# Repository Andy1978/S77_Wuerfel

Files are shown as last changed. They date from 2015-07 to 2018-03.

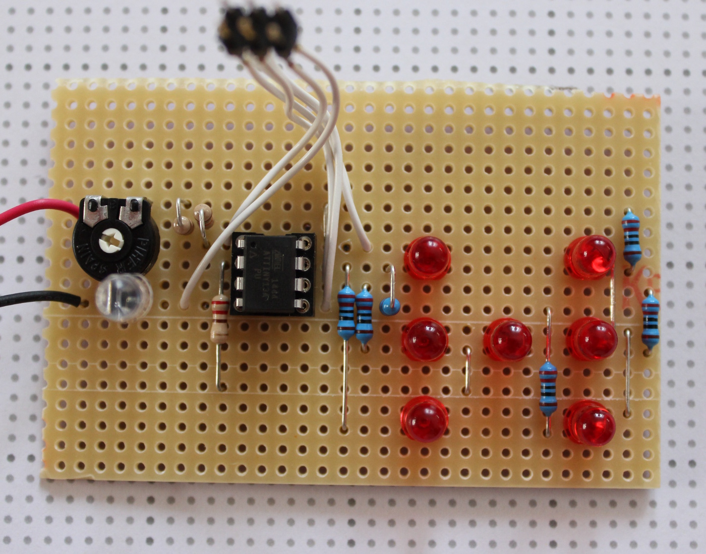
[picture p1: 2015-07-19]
doc/Aufbau.jpg

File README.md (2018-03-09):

# S77_Wuerfel
Elektronischer Würfel für den Section77 Lötkurs

http://tech-chat.de/files/VID_20150719_164159_Section77_Wuerfel.mp4

## Bauteile

Umgerechnet auf einen Bausatz

Anz. | Reichelt Bestellnummer | Bezeichnung                                | Preis
-----|------------------------|--------------------------------------------|-------
1    | ATTINY 13A-PU          | Atmel AVR-RISC-Controller                  | 0,99 €
7    | SLH 56 RT              | LED, 5mm, superhell, eingefärbt, klar, rot | 0,63 €
1    | BPW 40                 | Fototransistor, Plastikgehäuse, bedrahtet  | 0,29 €
7    | METALL 220             | Metallschichtwiderstand 220 Ohm            | 0,175 €
1    | METALL 12,0K           | Metallschichtwiderstand 12,0 K-Ohm         | 0,049 €
1    | GS 8P                  | IC-Sockel, 8-polig, superflach, gedreht, vergold. | 0,18 €
1    | TASTER 9302            | Kurzhubtaster 6x6mm, Höhe: 5,0mm, 12V, vertikal | 0,10 €
1    | H25SR160               | Streifenrasterplatine, Hartpapier, 160x100mm | 1,50 €, wird noch aufgeteilt
3    | aus GP AL40 AA         | Alkaline Mignon Aus 40er Pack              | 0,79€
1    | HALTER 3XUM3-DK        | Halter für 3 Mignonzellen (AA), Druckknopf | 0,40 €
1    | CLIP HQ9V-T            | Batterieclip für 9-Volt-Block, High-Quality, T-Form | 0,30€

## Abhängigkeiten unter GNU/Linux

* avr-gcc (Compiler für AVR µController)
* avr-libc
* avrdude (zum Übertragen der firmware)
* kicad (Für den Schaltplan)

In Debian basierten Distro z.B. über
```
sudo apt-get update
sudo apt-get install gcc-avr avr-libc avrdude kicad
```
zu installieren.

## Firmware compilieren und mit avrdude über USBasp flashen
```
cd src
make
make program
```

## udev rules für USBasp
```
$ cat /etc/udev/rules.d/45-avrusb.rules 
ATTRS{idVendor}=="16c0", ATTRS{idProduct}=="05dc", MODE="0660", GROUP="plugdev"
```

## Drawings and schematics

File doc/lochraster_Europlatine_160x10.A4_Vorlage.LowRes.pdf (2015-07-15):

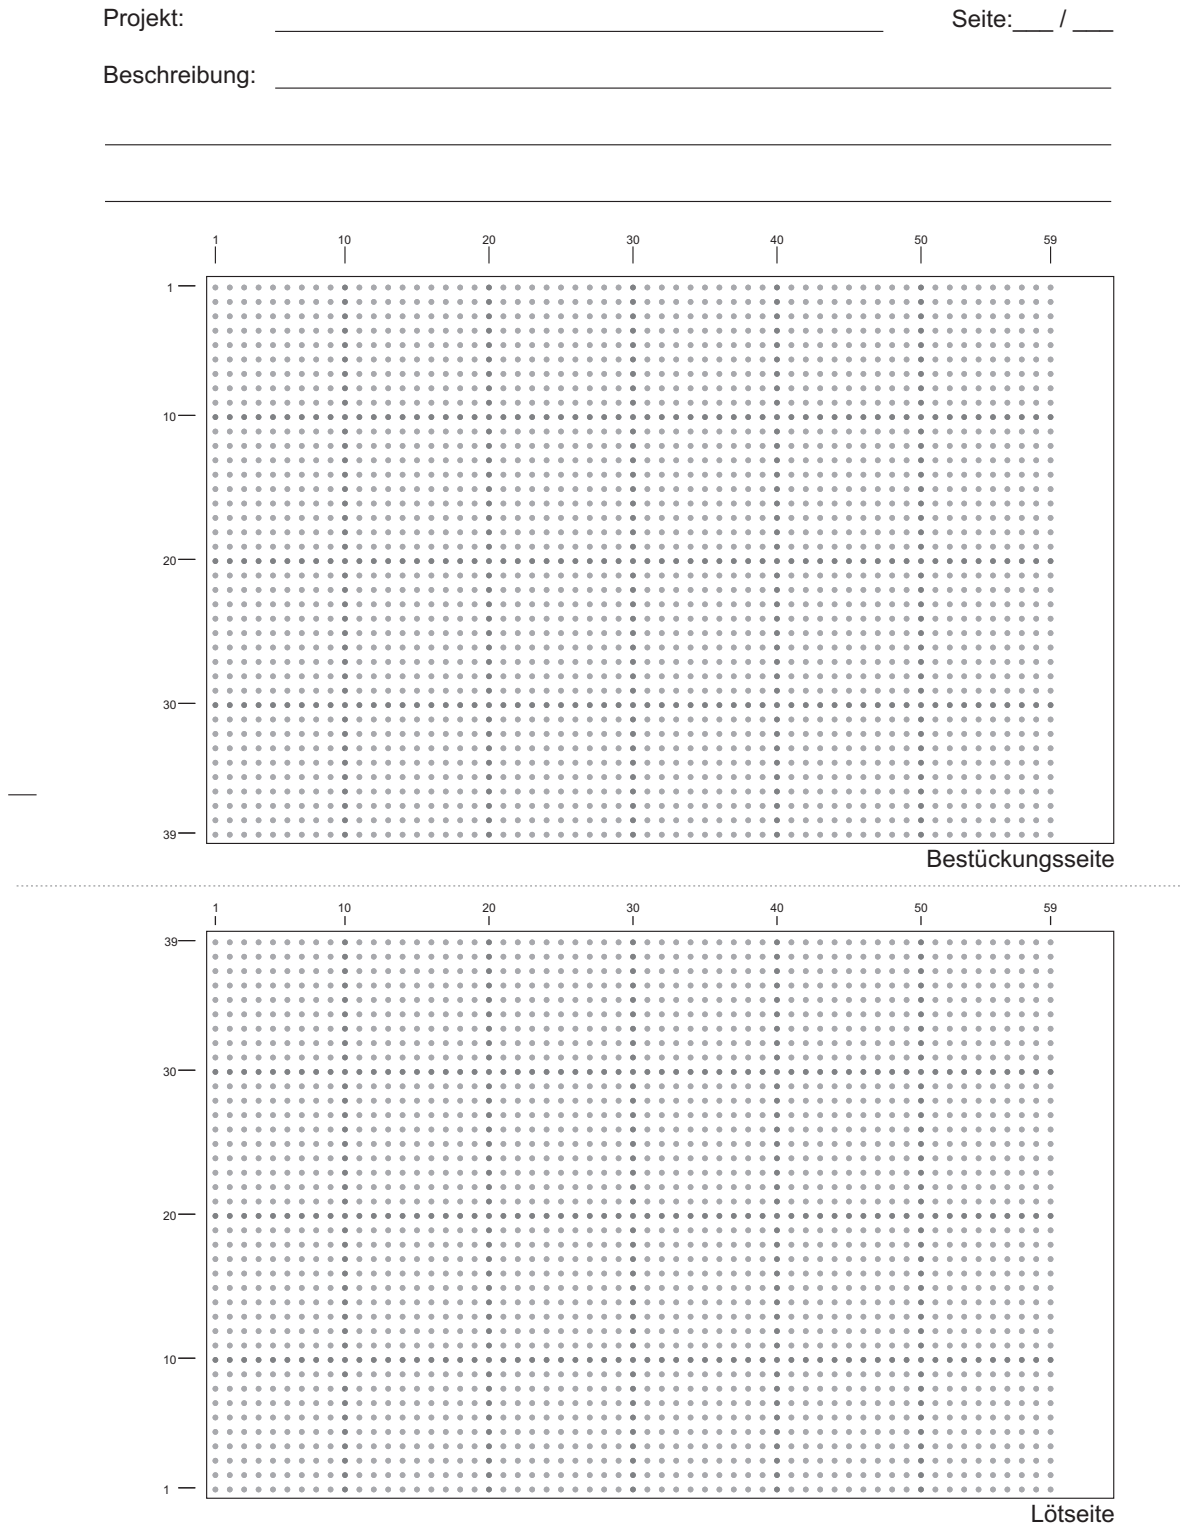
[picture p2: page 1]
Lötseite; Bestückungsseite; Projekt:; Seite:___ / ___; Beschreibung:

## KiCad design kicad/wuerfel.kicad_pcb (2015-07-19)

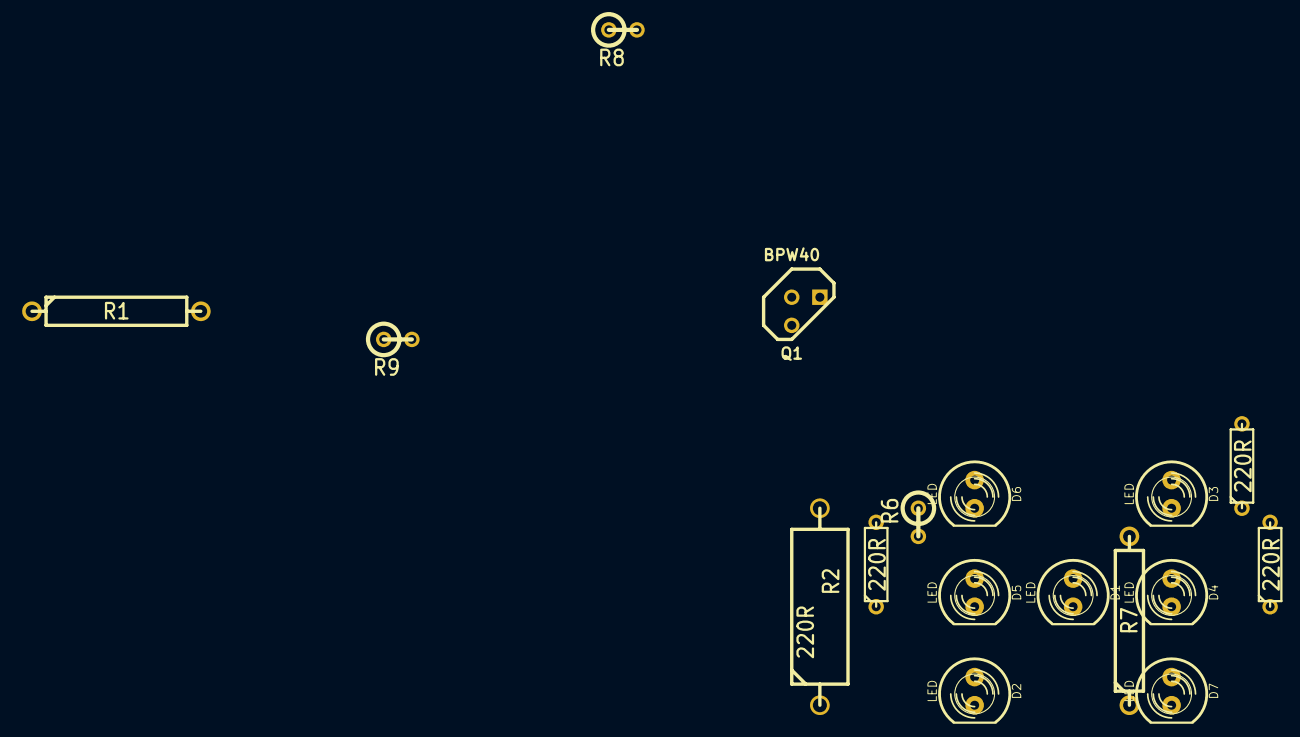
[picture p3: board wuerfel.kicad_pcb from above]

Board: 2 copper layers, 17 parts (0 on the bottom side), 11 nets, no tracks yet.

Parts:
D1, D2, D3, D4, D5, D6, D7: LED; LED-5MM
Q1: BPW40; TO92
R1, R7: 220R; R6
R2: 220R; R7
R3, R4, R5: 220R; R3
R6: 220R; R1
R8: 12K; R1
R9: 10K; R1

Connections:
unnamed: D3.2, R3.1
unnamed: R4.2, R5.2
unnamed: D2.2, R2.1
unnamed: D4.2, R4.1
unnamed: D5.2, R5.1
unnamed: D1.2, R1.1
unnamed: D6.2, R6.1
unnamed: D7.2, R7.1
unnamed: R2.2, R3.2
unnamed: R6.2, R7.2
VCC: D1.1, D2.1, D3.1, D4.1, D5.1, D6.1, D7.1, R8.1, R9.1

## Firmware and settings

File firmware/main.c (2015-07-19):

/*
    Copyright 2015 Andreas Weber <section77@tech-chat.de>

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
    You should have received a copy of the GNU General Public License
    along with this program.  If not, see <http://www.gnu.org/licenses/>.
*/

/**********************************************************************

  Section 77 Würfel
  Firmware für ATTiny13A

  Autor: Andreas Weber
  src: https://github.com/Andy1978/S77_Wuerfel/firmware
  changelog: 06.07.2015 angelegt

  Schaltplan in ../kicad.
  Es gibt 4 LED Gruppen (Im Schematic G0..G3):
  G0 an PB0, G1 and PB1 usw. bis G3 an PB3

  (0)       (2)

  (1)  (3)  (1)

  (2)       (0)

  Somit ergibt sich:
  Wert -> low tetrade PORTB
  1    -> 0b0111 = 0x7
  2    -> 0b1110 = 0xE
  3    -> 0b0110 = 0x6
  4    -> 0b1010 = 0xA
  5    -> 0b0010 = 0x2
  6    -> 0b1000 = 0x8

  * Phototransistor BPW40 an PB4 (ADC2)

***********************************************************************/

#include <stdlib.h>
#include <avr/io.h>
#include <avr/interrupt.h>
#include <util/delay.h>

// Siehe Erklärung oben
char numbers[7] = {0xF, 0x7, 0xE, 0x6, 0xA, 0x2, 0x8};

// F_CPU ist 1.2 MHz (interner RC Oszillator, s.a. Makefile)
// Clk-Prescaler ist 8 (siehe TCCR0B)
// OCR0A ist 150
//
// Damit ergibt sich eine Aufruffrequenz von
// 1200000 / 8 / 150 = 1kHz

ISR(TIM0_COMPA_vect)
{
  /*
  // Im Sekundentakt von 0..6 zählen
  static int c=0;
  static int step=0;
  c++;

  if (c==1000)
    {
      PORTB = (PORTB & 0xF0) | numbers[step++];

      if (step>6)
        step = 0;
      c = 0;
    }
  */
}

// Eine normale Wandlung dauert 13 clock cycles
// -> Aufruf mit ca. 1200000/128/13 = 721Hz

ISR(ADC_vect)
{
  // Wenn der analoge Eingang über einen Schwellwert (0.5 * VCC) steigt,
  // schnell durchzählen
  static int num = 1;
  if (ADC > 512)
    {
      PORTB = (PORTB & 0xF0) | numbers[num++];

      if (num > 6)
        num = 1;
    }
}

int main(void)
{
  // Die 4 Pins an denen die LEDs hängen sind Ausgänge
  DDRB = _BV(PB0) |  _BV(PB1) | _BV(PB2) | _BV(PB3);

  /*** TIMER0 ***/
  OCR0A = 150;
  //CTC = Clear Timer on Compare match S.80
  //Normal port operation, OC0A disconnected
  TCCR0A = _BV(WGM01);

  //Prescaler=8 -> clk=150kHz
  TCCR0B = _BV(CS01);

  //On Compare match Interrupt Enable for timer 0
  TIMSK0 |= _BV(OCIE0A);

  /*** ADC ***/
  //Prescaler 128 = 9.375kHz ADC Clock, AutoTrigger, Interrupts enable
  ADCSRA = _BV(ADEN) | _BV(ADPS0) | _BV(ADPS1) | _BV(ADPS2) | _BV(ADATE) | _BV(ADSC) | _BV(ADIE);

  //ADC Auto Trigger Source = Free Running
  //ACME = 0
  ADCSRB = 0;

  // REFS0 = 0 : Vcc used as analog reference
  // ADLAR = 0
  // MUX = ADC2 (PB4)
  ADMUX = 2;

  //enable global interrupts
  sei();

  for (;;)    /* main event loop */
    {
      // nichts tun, es wird alles in den Interrupts erledigt
      ;
    }
  return 0;
}

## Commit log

2015-07-06 Stub für firmware angelegt, Readme erweitert
    [wuerfel.sch]
2015-07-19 Makefile MCU gefixt, erster LED Test
2015-07-19 Schalter aus Design entfernt, einfache Implementation fertiggestellt
    [wuerfel.sch]
2015-07-19 KiCAD Zeichnungen erweitert (noch nicht fertig), Readme aktualisiert
    [wuerfel.kicad_pcb]
2015-07-19 Bild des Aufbaus mit Unterbrechungen auf der Rückseite

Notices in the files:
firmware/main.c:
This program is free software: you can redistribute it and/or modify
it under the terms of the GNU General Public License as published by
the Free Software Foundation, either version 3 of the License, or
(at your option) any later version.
